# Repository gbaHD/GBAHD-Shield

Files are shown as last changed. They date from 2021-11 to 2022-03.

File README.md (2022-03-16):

# gbaHD Shield
This is a shield for the [gbaHD project](https://github.com/zwenergy/gbaHD).  

# What is the gbaHD Shield?
The gbaHD Shield is an easy solution to interface with the Spartan Edge Accelerator Board used for the gbaHD Project and the GBA / GBA-SP itself.

It has the following features.
- Connects via female headers to the Edge board (shield)
- Has a FFC 40 pin connector for OGBA LCD connector. Need Type-B Cable (Reverse) vvv=======^^^
- Has a FFC 32 pin connector for OGBA LCD connector. Need Type-B Cable (Reverse) vvv=======^^^
- Has a FFC 34 pin connector for GBA-SP LCD connector. Need Type-A Cable (Direct) vvv=======vvv
- Has a FFC 16 pin connector for controls with a wire up board. Need Type-B Cable (Reverse) vvv=======^^^
- Has a ATMEGA328p / ATMEGA168p / ATMEGA88p for using a SNES connector to control the GBA.
- Has a high-side switch for GBA power controls (IGR).
- Optional Flex-Cable to solder on the the CPU of the GBA and the GBASP
- Unused ATMEGA-Pins are broken out as testpoints on the top and bottom side for future features.

In cooperation with bbsan the featureset of the Shield has been expanded.
The new features are:
- Update of the ATMEGA Firmwre over the ESP32
- Bluetooth-Controller Support
- WebUI
- OTA-Update of the ESP32, ATMEGA and Bitstreams over the WebUI
- Bitstream selection (720p / 1080p) in the WebUI

## Special Thanks
- @zwenergy0 for the gbaHD-Project itself
- @bbsan2k for all the hard work with the ESP32-Side
- @ManCloud for the Shield design itself
- @jotheripper for the awesome cases (https://www.prusaprinters.org/social/170041-jotheripper/about)
- @ricardoquesada for the BluePad-Implementation (https://github.com/ricardoquesada/bluepad32)

## Contributing
If you wish to contribute, see something wrong or want to add a feature please make a pull request or leave an issue!

## BOM
|Reference	|Value |
|---	|---						|
|C1,C3	|100nF - 0805|
|C2	|22u - 0805|
|C4	|47uF - 0805|
|R1	|2.2k - 0805|
|R2,R7,R6	|1k - 0805|
|R3,R4,R8	|10K - 0805|
|R5	|500 - 0805|
|D1	|LED RED - 0805|
|D2	|LED GREEN - 0805|
|U1	|AZ1117R-ADJ - SOT-89-3|
|U2,U3	|74HC595 - SOIC-16|
|U4	|SNES_7PIN|
|U5	|ATmega328P-AU|
|U5-Alternative	|ATmega168P-AU|
|U5-Alternative-Alternative	|ATmega88PA-AU|
|Q1	|SI2301CDS-T1-GE3 - SOT-23|
|Q2,Q3	|2N7002 - SOT-23|
|SW1	|XKB-TS-1185EC-C-D-B|
|J2			|32Pin 0.5 Pitch, bottom contacts|
|J3			|34Pin 0.5 Pitch, bottom contacts|
|J4			|16Pin 0.5 Pitch, bottom contacts|
|J5			|40Pin 0.5 Pitch, bottom contacts|
|J6	|PinHeader 1x6 2.54mm|
|J7,J9	|PinHeader 1x8 2.54mm|
|J8,J10	|PinHeader 1x10 2.54mm|

## Images
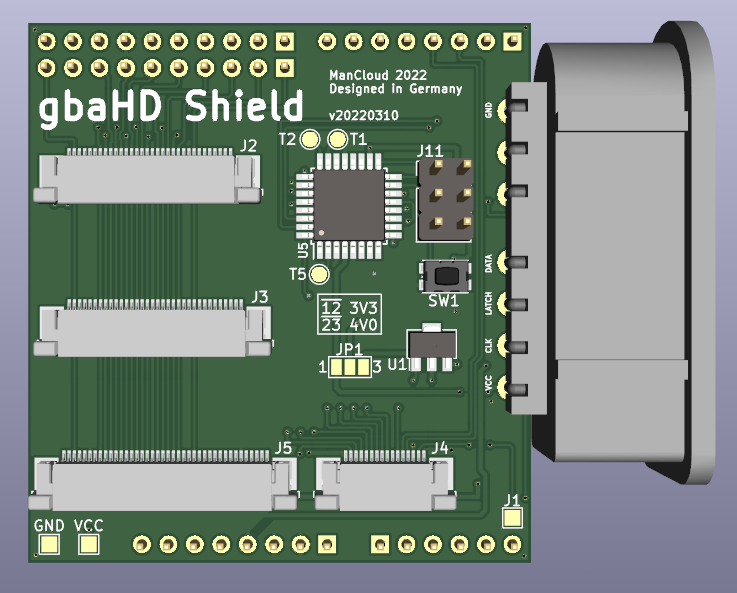
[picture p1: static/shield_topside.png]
PCB Top-Side PCB

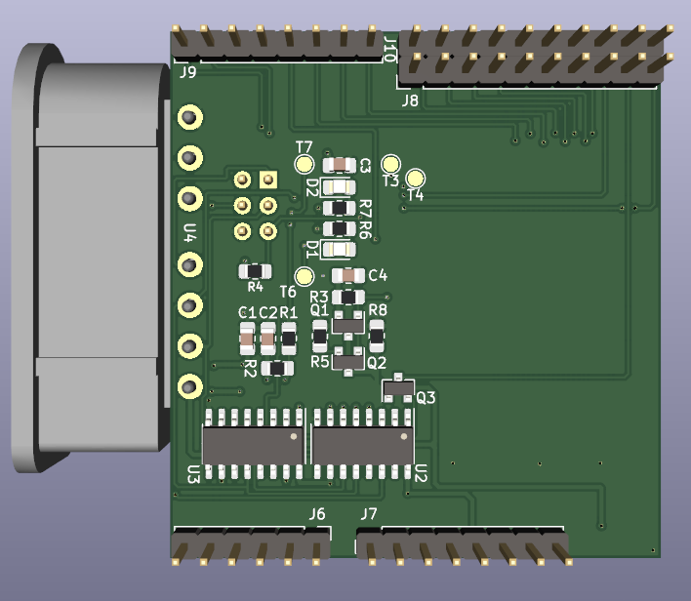
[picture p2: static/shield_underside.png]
PCB Under-Side PCB


Breakout-Board for the OGBA

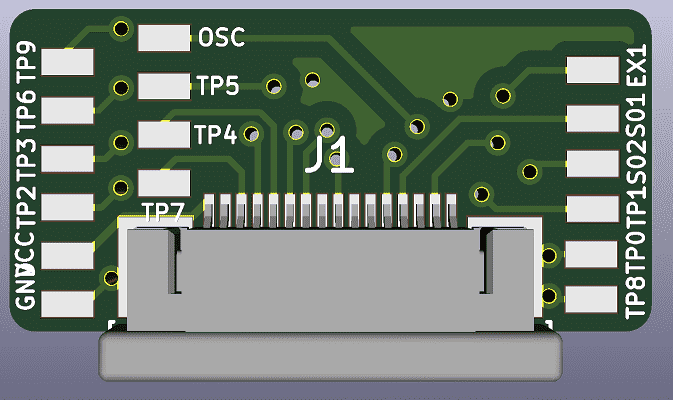
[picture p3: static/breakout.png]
Breakout OGBA Breakout PCB


Breakout-Board for the GBA-SP

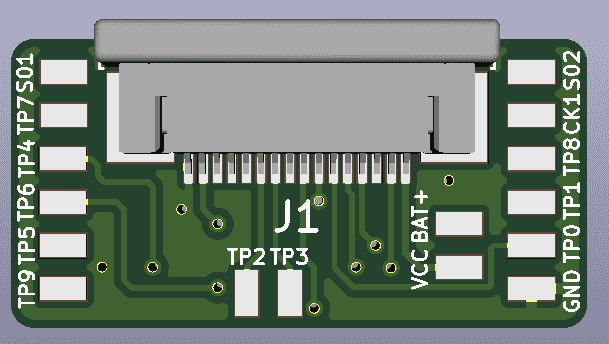
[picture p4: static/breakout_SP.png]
Breakout_GBA-SP Breakout PCB for GBA SP


Flex-Cable for the GBA

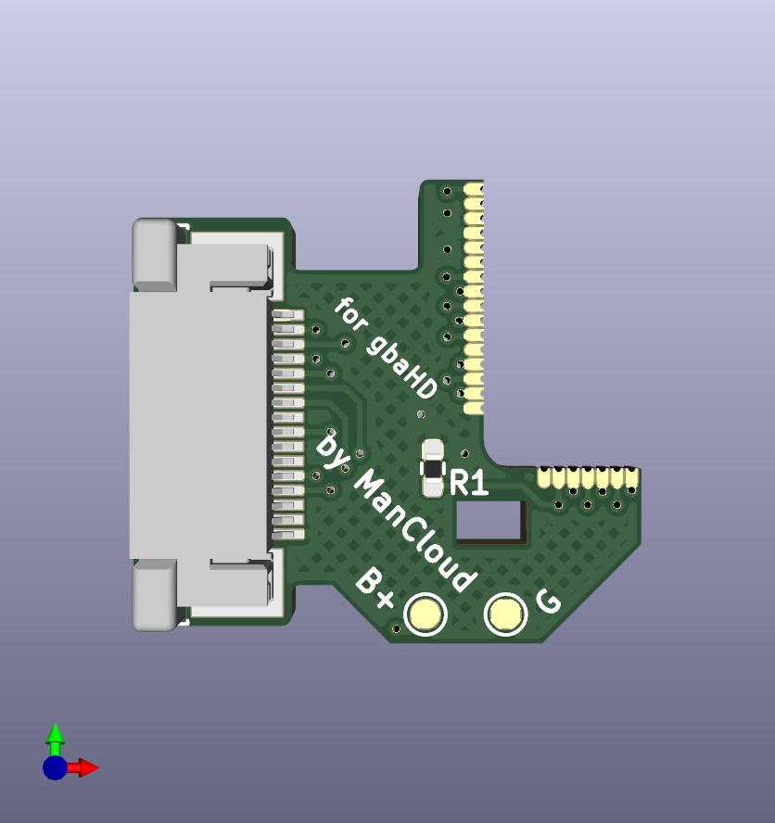
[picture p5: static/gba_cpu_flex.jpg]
Breakout_GBA-SP Flex for the GBA CPU


Flex-Cable for the GBA-SP

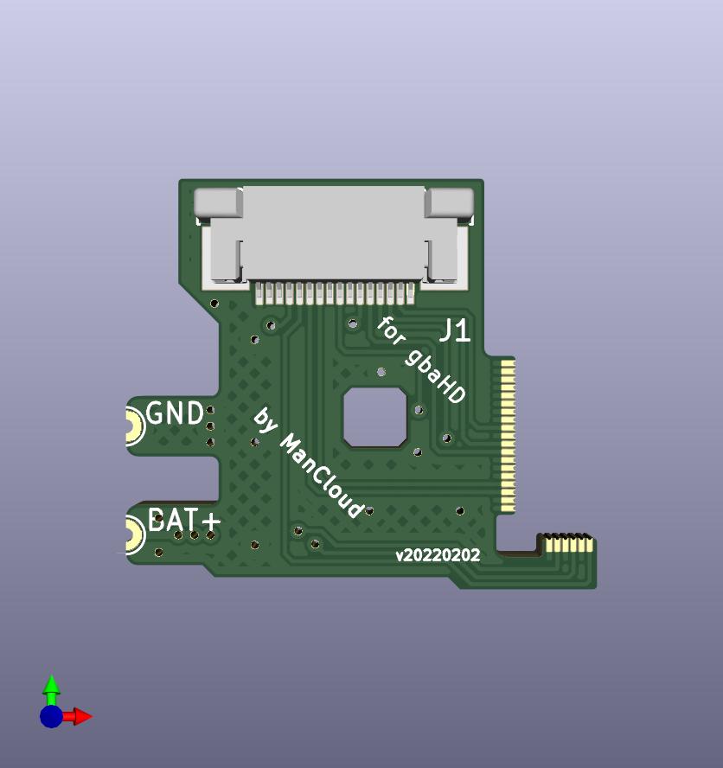
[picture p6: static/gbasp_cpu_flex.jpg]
Breakout_GBA-SP Flex for the GBA CPU


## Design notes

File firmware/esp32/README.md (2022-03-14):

# gbaHD ESP32 Software for SAE board

This folder contains the ESP32 Software for usage with zwenergys gbaHD project.

## Features:

**Bluetooth Controller Support:**

The ESP32 Micro Controller contains an onboard wireless and Bluetooth Modem.
This Bluetooth Modem can be used to connect with a Wireless Bluetooth Controller.
This project makes use of Ricardo Quesadas *Bluepad32* library (see [2]) for the whole Bluetooth Controller communication setup.
Furthermore it uses TWI to communicate all key presses to the ATMega on the gbaHD Shield, which then publishs the key presses to the GBA.
A simplified mapping is provided in the *Settings* tab on gbaHDs Web Interface.

**OTA Update:**

To simplify all further updates by zwenergy or for the esp32, OTA functionality was added.
When opening the Web Interface on http://gbahd.local it automatically checks, if a new bitstream update or a new esp32 software is available. You can directly update using the *OTA Update* Button on the Web Interface.
To connect to a WiFi network, create a file called "wifi.cfg" with your wifi credentials on an sd card. Insert it and connection to this network will be established:
```
ssid=MyWifiSSID
password=MyWifiPasswordIsSecure
```

**SD Card Update:**

If you want to keep your device offline but still want to experience the latest and greatest features, you can simply add all Update files to SD Card. On the first boot afterwards, gbaHD will then copy these updates to its internal memory.

File            |   Update
----------------|------------
esp32.bin       | ESP32
spiffs.bin      | ESP32 data partition
720p.bit        | 720P Bitstream
1080p.bit       | 1080P Bitstream

**Bitstream Selection:**

As per default, gbaHD will be started with the 720P Bitstream. In the *Settings* tab of the Web Interface, you can change it to 1080P.

## Thanks to...

- Zwenergy for gbaHD [1]
- ManCloud for coordination and gbaHD shield
- Ricardo Quesada for Bluepad32 [2]
- Arduino and Espressif for arduino-esp32
- PicoCSS team for PicoCSS [3]
- jotheripper for his gbaHD Case
- derKevin for test feedback
- bbsan for ESP32 SW

[1] gbaHD:
https://github.com/zwenergy/gbaHD

[2] Bluepad32:
https://gitlab.com/ricardoquesada/bluepad32

[3] PicoCSS:
https://picocss.com

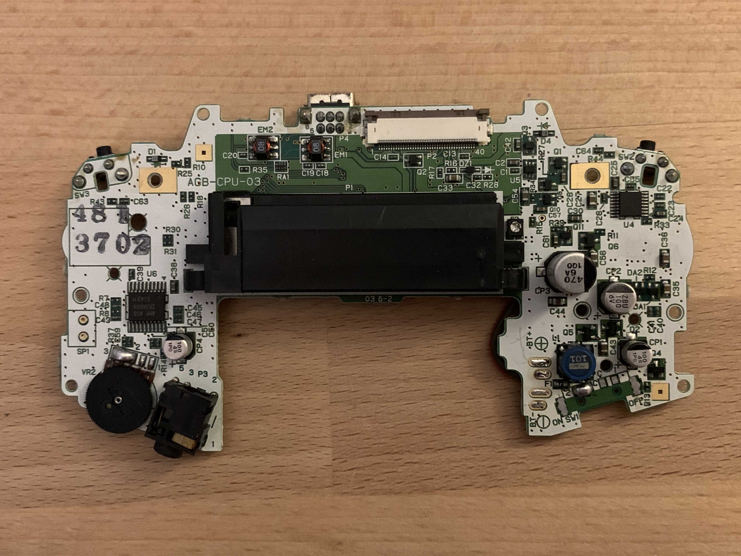
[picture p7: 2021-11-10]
static/wiki/ogba_overview_underside.jpg

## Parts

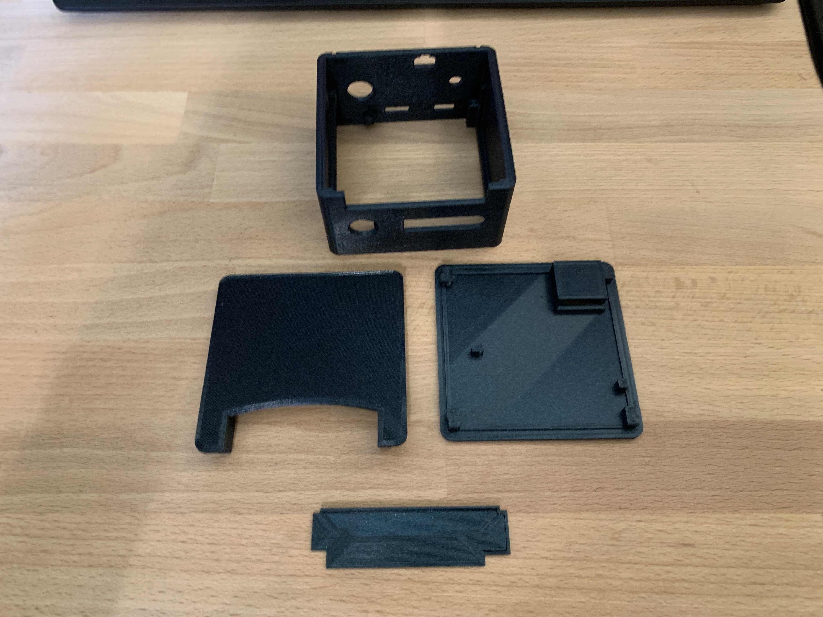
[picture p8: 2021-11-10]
static/wiki/case_sp/case0_parts1.jpg

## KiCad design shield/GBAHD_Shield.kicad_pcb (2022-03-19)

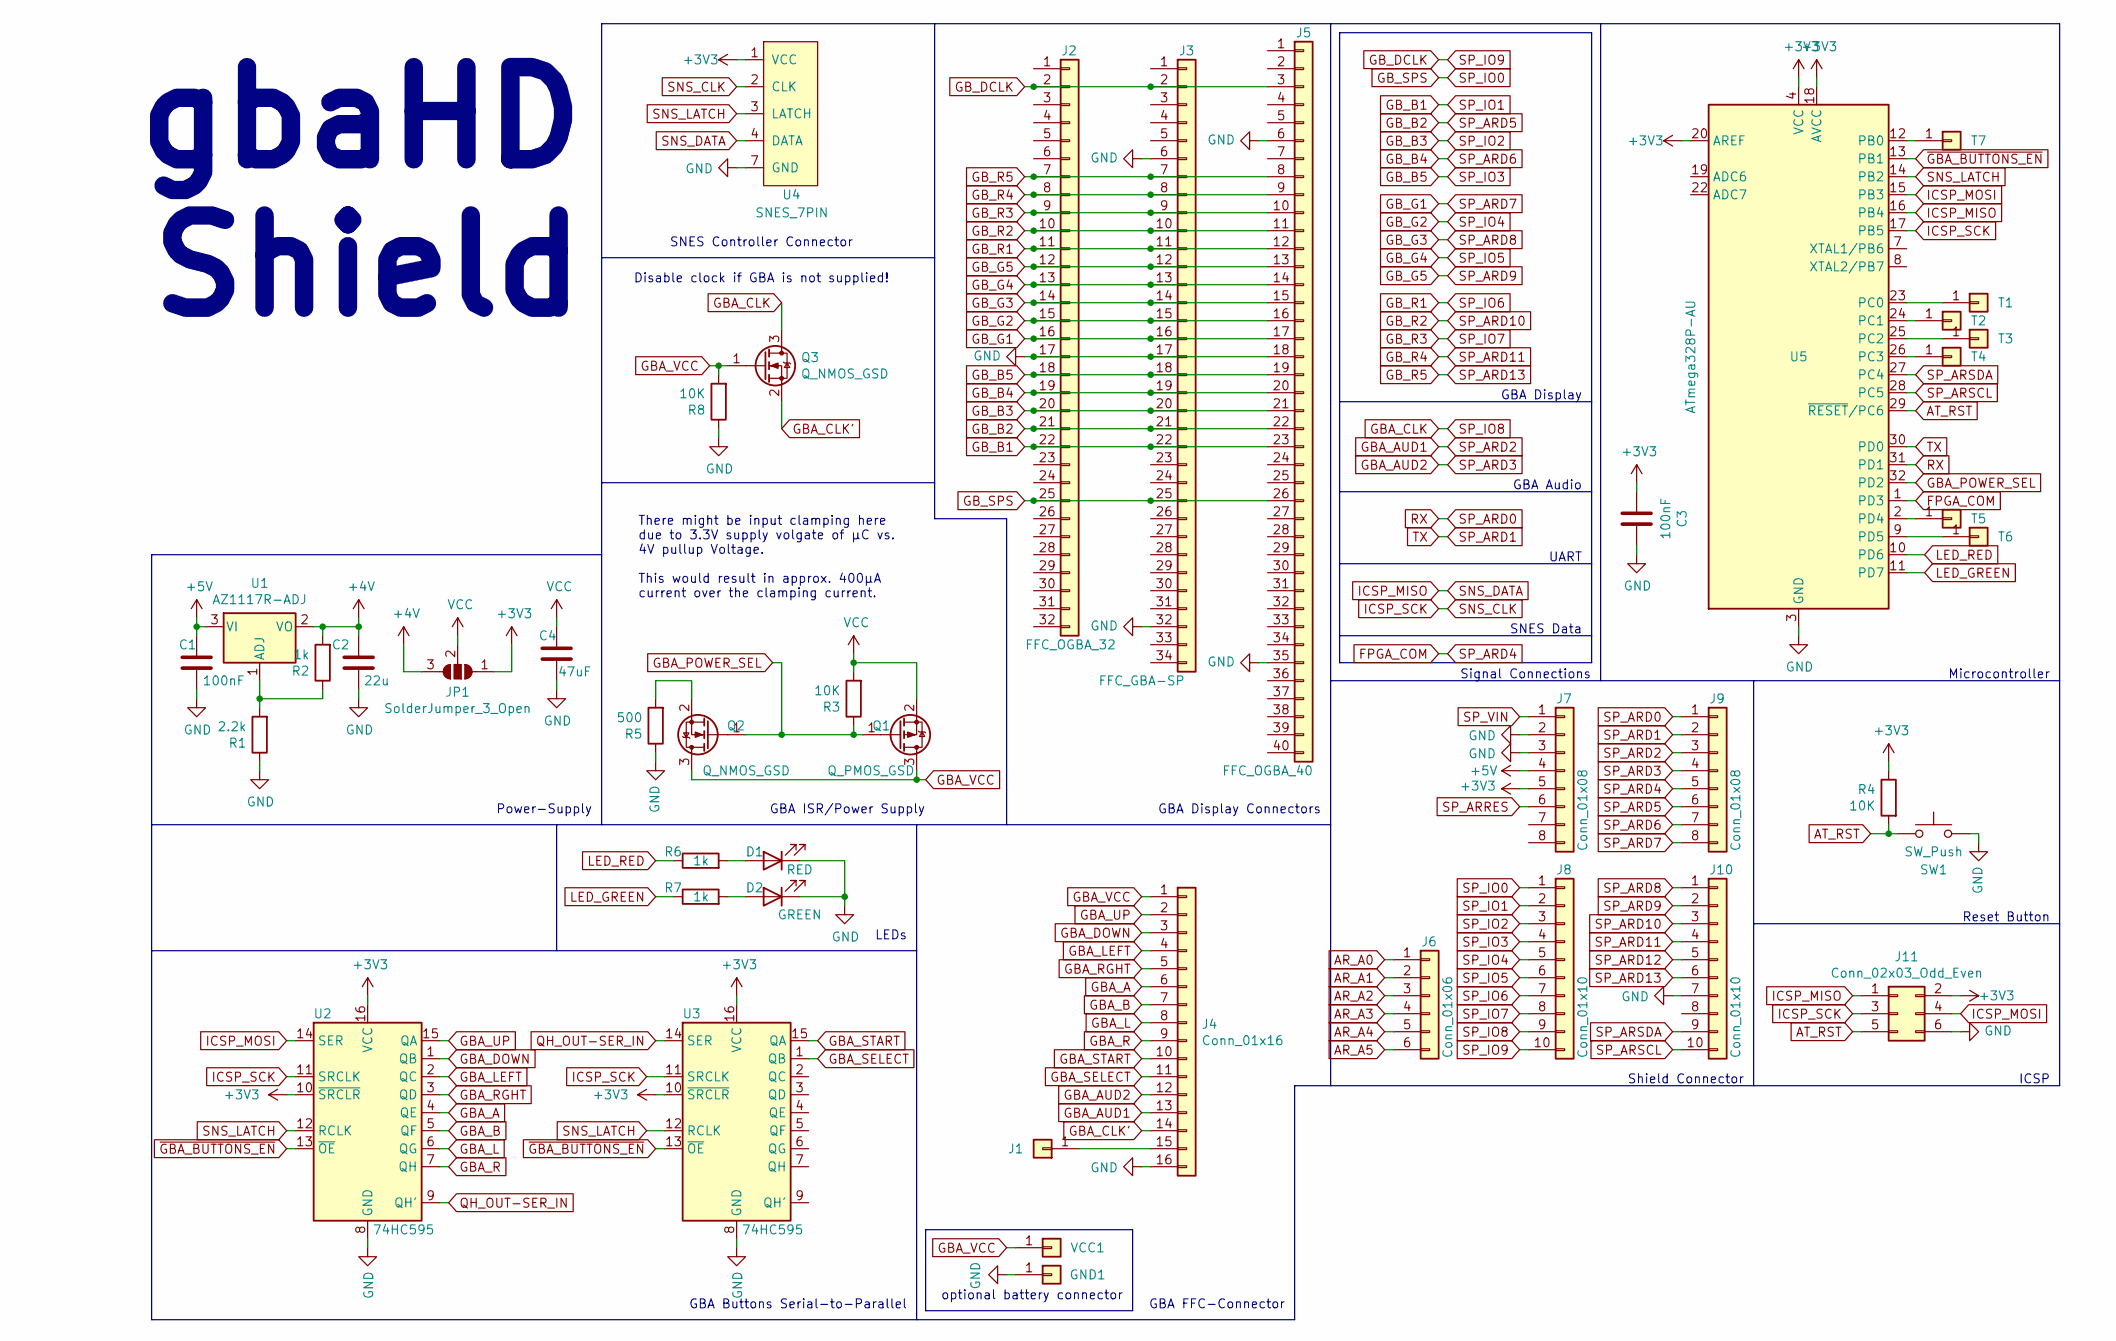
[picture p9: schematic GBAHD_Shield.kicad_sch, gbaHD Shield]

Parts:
C1, C3: 100nF; C_0805_2012Metric_Pad1.18x1.45mm_HandSolder
C2: 22u; C_0805_2012Metric_Pad1.18x1.45mm_HandSolder
C4: 47uF; C_0805_2012Metric_Pad1.18x1.45mm_HandSolder
D1: RED; LED_0805_2012Metric_Pad1.15x1.40mm_HandSolder
D2: GREEN; LED_0805_2012Metric_Pad1.15x1.40mm_HandSolder
GND1: Conn_01x01; TestPoint_Pad_1.5x1.5mm
J1: Conn_01x01; TestPoint_Pad_1.5x1.5mm
J2: FFC_OGBA_32; TE_3-1734839-2_1x32-1MP_P0.5mm_Horizontal
J3: FFC_GBA-SP; TE_3-1734839-4_1x34-1MP_P0.5mm_Horizontal
J4: Conn_01x16; TE_1-1734839-6_1x16-1MP_P0.5mm_Horizontal
J5: FFC_OGBA_40; TE_4-1734839-0_1x40-1MP_P0.5mm_Horizontal
J6: Conn_01x06; PinHeader_1x06_P2.54mm_Vertical
J7, J9: Conn_01x08; PinHeader_1x08_P2.54mm_Vertical
J8, J10: Conn_01x10; PinHeader_1x10_P2.54mm_Vertical
J11: Conn_02x03_Odd_Even; PinHeader_2x03_P2.54mm_Vertical
JP1: SolderJumper_3_Open; SolderJumper-3_P1.3mm_Open_Pad1.0x1.5mm_NumberLabels
Q1: Q_PMOS_GSD; SOT-23
Q2, Q3: Q_NMOS_GSD; SOT-23
R1: 2.2k; R_0805_2012Metric_Pad1.20x1.40mm_HandSolder
R2, R6, R7: 1k; R_0805_2012Metric_Pad1.20x1.40mm_HandSolder
R3, R4, R8: 10K; R_0805_2012Metric_Pad1.20x1.40mm_HandSolder
R5: 500; R_0805_2012Metric_Pad1.20x1.40mm_HandSolder
SW1: SW_Push; SW_Push_1P1T_NO_CK_KMR2
T1, T2, T3, T4, T5, T6, T7: Conn_01x01; TestPoint_Pad_D1.5mm
U1: AZ1117R-ADJ; SOT-89-3
U2, U3: 74HC595; SOIC-16_3.9x9.9mm_P1.27mm
U4: SNES_7PIN
U5: ATmega328P-AU; TQFP-32_7x7mm_P0.8mm
VCC1: Conn_01x01; TestPoint_Pad_1.5x1.5mm

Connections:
+3V3: C3.2, J7.5, J11.2, JP1.1 (A), R4.1, U2.10 (~SRCLR), U2.16 (VCC), U3.10 (~SRCLR), U3.16 (VCC), U4.1 (VCC), U5.4 (VCC), U5.6 (VCC), U5.18 (AVCC), U5.20 (AREF)
+4V: C2.2, JP1.3 (B), R2.2, U1.2 (VO)
+5V: C1.2, J7.4, U1.3 (VI)
AR_A0: J6.1
AR_A1: J6.2
AR_A2: J6.3
AR_A3: J6.4
AR_A4: J6.5
AR_A5: J6.6
AT_RST: J11.5, R4.2, SW1.1, U5.29 (~RESET/PC6)
FPGA_COM: J9.5, U5.1 (PD3)
GBA_A: J4.6, U2.4 (QE)
GBA_AUD1: J4.13, J9.3
GBA_AUD2: J4.12, J9.4
GBA_B: J4.7, U2.5 (QF)
GBA_CLK: J8.9, Q3.3 (D)
GBA_CLK': J4.14, Q3.2 (S)
GBA_DOWN: J4.3, U2.1 (QB)
GBA_L: J4.8, U2.6 (QG)
GBA_LEFT: J4.4, U2.2 (QC)
GBA_POWER_SEL: Q1.1 (G), Q2.1 (G), R3.1, U5.32 (PD2)
GBA_R: J4.9, U2.7 (QH)
GBA_RGHT: J4.5, U2.3 (QD)
GBA_SELECT: J4.11, U3.1 (QB)
GBA_START: J4.10, U3.15 (QA)
GBA_UP: J4.2, U2.15 (QA)
GBA_VCC: J4.1, Q1.3 (D), Q2.3 (D), Q3.1 (G), R8.2, VCC1.1
GB_B1: J2.22, J3.22, J5.23, J8.2
GB_B2: J2.21, J3.21, J5.22, J9.6
GB_B3: J2.20, J3.20, J5.21, J8.3
GB_B4: J2.19, J3.19, J5.20, J9.7
GB_B5: J2.18, J3.18, J5.19, J8.4
GB_DCLK: J2.2, J3.2, J5.3, J8.10
GB_G1: J2.16, J3.16, J5.17, J9.8
GB_G2: J2.15, J3.15, J5.16, J8.5
GB_G3: J2.14, J3.14, J5.15, J10.1
GB_G4: J2.13, J3.13, J5.14, J8.6
GB_G5: J2.12, J3.12, J5.13, J10.2
GB_R1: J2.11, J3.11, J5.12, J8.7
GB_R2: J2.10, J3.10, J5.11, J10.3
GB_R3: J2.9, J3.9, J5.10, J8.8
GB_R4: J2.8, J3.8, J5.9, J10.4
GB_R5: J2.7, J3.7, J5.8, J10.6
GB_SPS: J2.25, J3.25, J5.26, J8.1
GND: C1.1, C2.1, C3.1, C4.1, D1.1 (K), D2.1 (K), GND1.1, J2.17, J3.6, J3.17, J3.32, J4.16, J5.6, J5.18, J5.35, J7.2, J7.3, J10.7, J11.6, R1.1, R5.1, R8.1, SW1.2, U2.8 (GND), U3.8 (GND), U4.7 (GND), U5.3 (GND), U5.5 (GND), U5.21 (GND)
ICSP_MISO: J11.1, U4.4 (DATA), U5.16 (PB4)
ICSP_MOSI: J11.4, U2.14 (SER), U5.15 (PB3)
ICSP_SCK: J11.3, U2.11 (SRCLK), U3.11 (SRCLK), U4.2 (CLK), U5.17 (PB5)
LED_GREEN: R7.1, U5.11 (PD7)
LED_RED: R6.1, U5.10 (PD6)
unnamed: D1.2 (A), R6.2
unnamed: D2.2 (A), R7.2
unnamed: J1.1, J4.15
unnamed: Q2.2 (S), R5.2
unnamed: R1.2, R2.1, U1.1 (ADJ)
unnamed: T1.1, U5.23 (PC0)
unnamed: T2.1, U5.24 (PC1)
unnamed: T3.1, U5.25 (PC2)
unnamed: T4.1, U5.26 (PC3)
unnamed: T5.1, U5.2 (PD4)
unnamed: T6.1, U5.9 (PD5)
unnamed: T7.1, U5.12 (PB0)
QH_OUT-SER_IN: U2.9 (QH'), U3.14 (SER)
RX: J9.1, U5.31 (PD1)
SNS_LATCH: U2.12 (RCLK), U3.12 (RCLK), U4.3 (LATCH), U5.14 (PB2)
SP_ARD1: J9.2, U5.30 (PD0)
SP_ARD12: J10.5
SP_ARRES: J7.6
SP_ARSCL: J10.10, U5.28 (PC5)
SP_ARSDA: J10.9, U5.27 (PC4)
SP_VIN: J7.1
VCC: C4.2, JP1.2 (C), Q1.2 (S), R3.2
~GBA_BUTTONS_EN: U2.13 (~OE), U3.13 (~OE), U5.13 (PB1)

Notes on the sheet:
ICSP
GBA Buttons Serial-to-Parallel
GBA FFC-Connector
GBA ISR/Power Supply
SNES Data
optional battery connector
There might be input clamping here due to 3.3V supply volgate of µC vs. 4V pullup Voltage. This would result in approx. 400µA current over the clamping current.
Microcontroller
GBA Display Connectors
Shield Connector
gbaHD Shield
UART
LEDs
Power-Supply
Disable clock if GBA is not supplied!
SNES Controller Connector
Reset Button
Signal Connections
GBA Display
GBA Audio

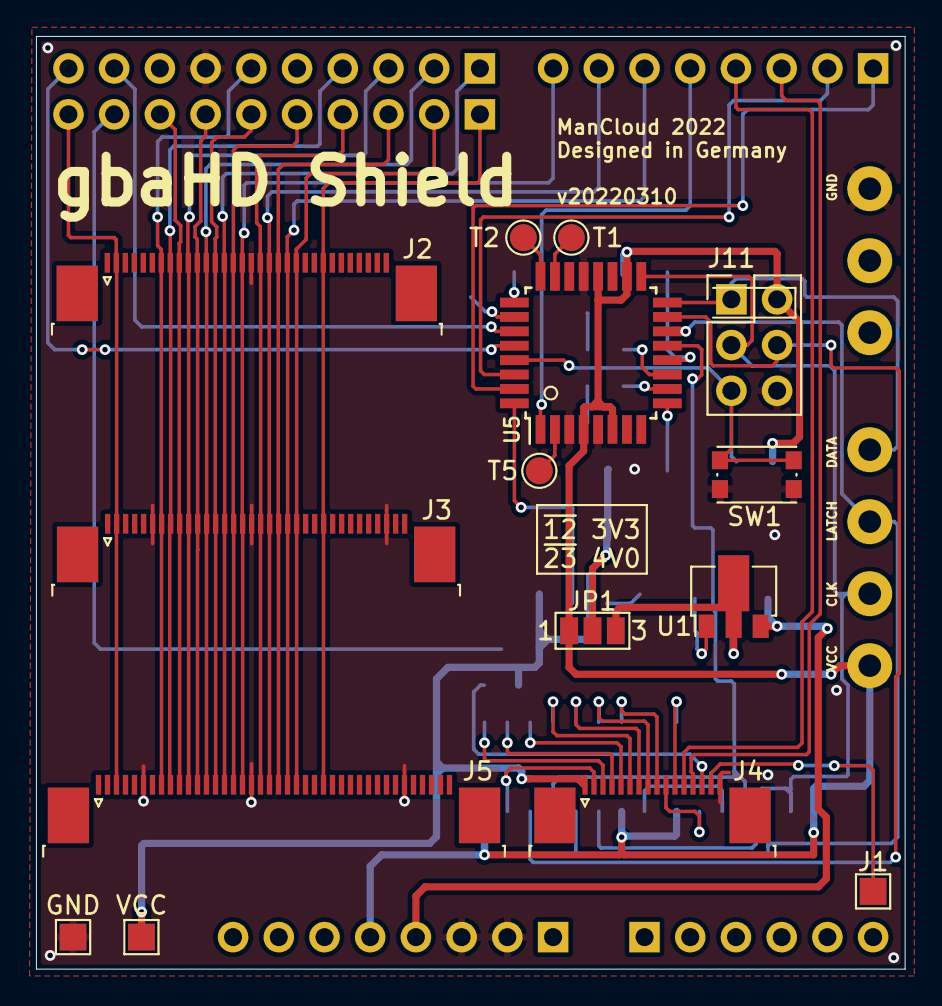
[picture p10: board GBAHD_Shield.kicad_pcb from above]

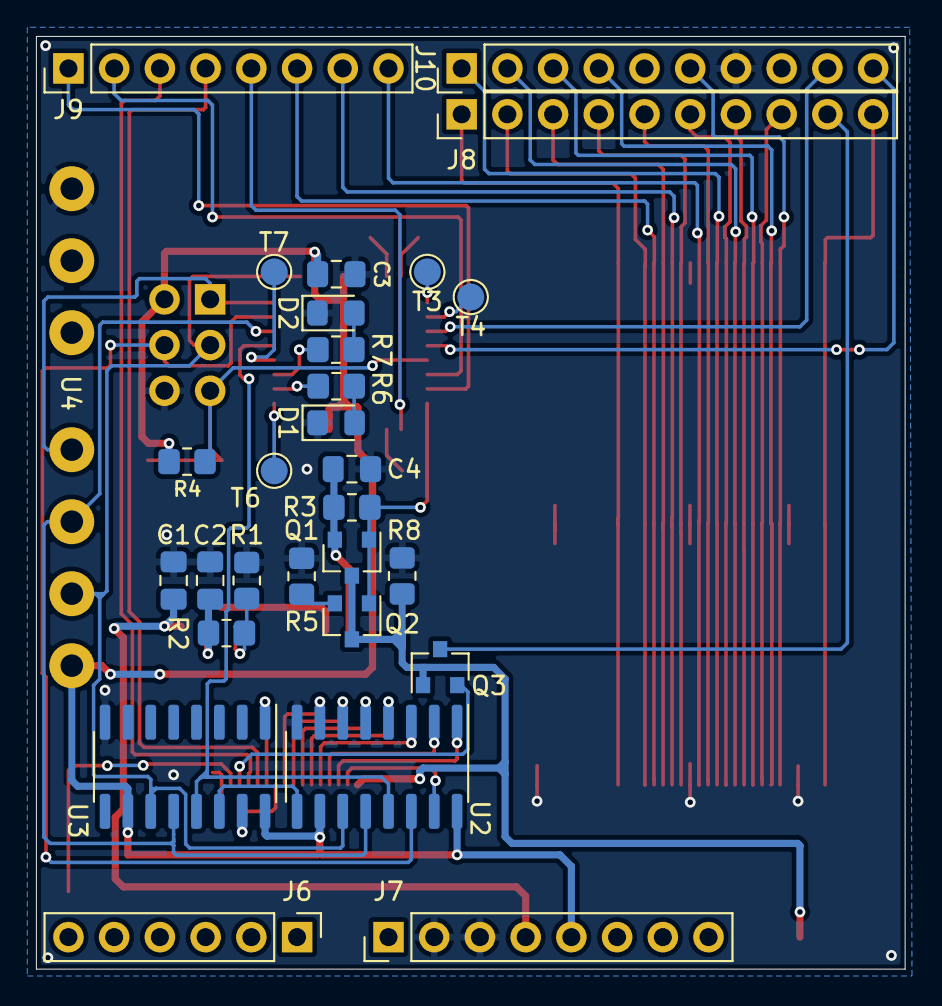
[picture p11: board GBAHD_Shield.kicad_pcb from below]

Board: 2 copper layers, 48.3 x 51.8 mm, 44 parts (29 on the bottom side), 64 nets.

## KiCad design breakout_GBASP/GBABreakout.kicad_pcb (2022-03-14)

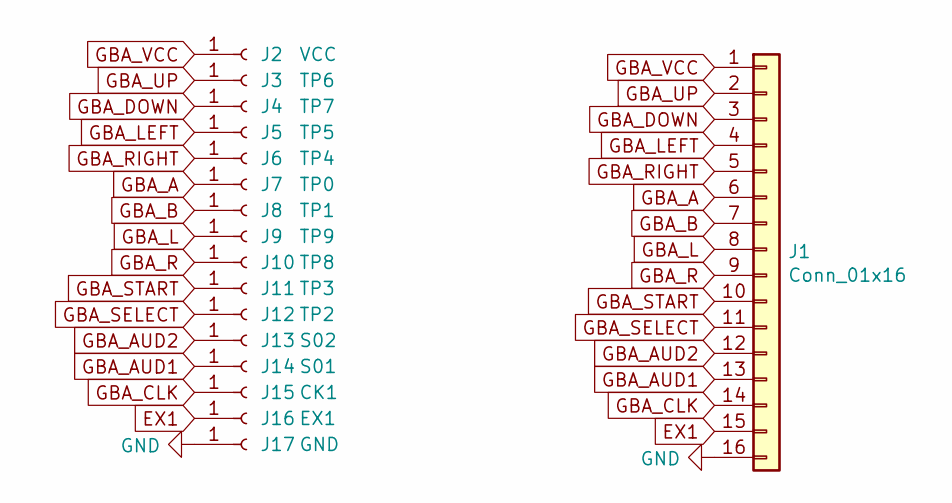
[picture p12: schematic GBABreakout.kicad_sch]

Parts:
J1: Conn_01x16; TE_1-1734839-6_1x16-1MP_P0.5mm_Horizontal
J2: VCC; SOLDER_PAD
J3: TP6; SOLDER_PAD
J4: TP7; SOLDER_PAD
J5: TP5; SOLDER_PAD
J6: TP4; SOLDER_PAD
J7: TP0; SOLDER_PAD
J8: TP1; SOLDER_PAD
J9: TP9; SOLDER_PAD
J10: TP8; SOLDER_PAD
J11: TP3; SOLDER_PAD
J12: TP2; SOLDER_PAD
J13: S02; SOLDER_PAD
J14: S01; SOLDER_PAD
J15: CK1; SOLDER_PAD
J16: EX1; SOLDER_PAD
J17: GND; SOLDER_PAD

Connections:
EX1: J1.15, J16.1
GBA_A: J1.6, J7.1
GBA_AUD1: J1.13, J14.1
GBA_AUD2: J1.12, J13.1
GBA_B: J1.7, J8.1
GBA_CLK: J1.14, J15.1
GBA_DOWN: J1.3, J4.1
GBA_L: J1.8, J9.1
GBA_LEFT: J1.4, J5.1
GBA_R: J1.9, J10.1
GBA_RIGHT: J1.5, J6.1
GBA_SELECT: J1.11, J12.1
GBA_START: J1.10, J11.1
GBA_UP: J1.2, J3.1
GBA_VCC: J1.1, J2.1
GND: J1.16, J17.1

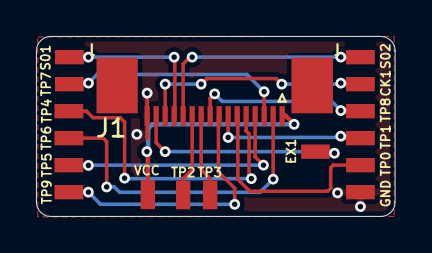
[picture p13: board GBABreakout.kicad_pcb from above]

Board: 2 copper layers, 19.9 x 10.0 mm, 17 parts (0 on the bottom side), 16 nets.

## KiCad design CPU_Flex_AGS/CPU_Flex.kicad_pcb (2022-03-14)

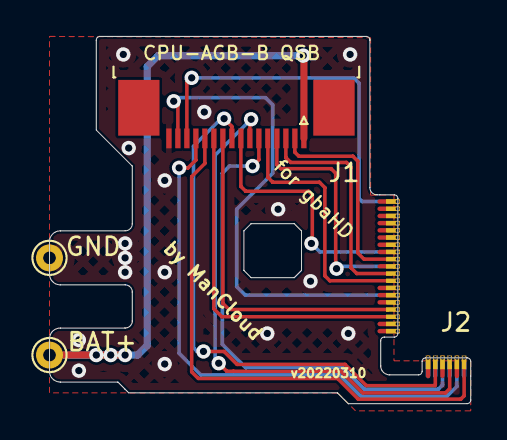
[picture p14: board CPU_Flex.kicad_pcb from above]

Board: 2 copper layers, 23.4 x 20.4 mm, 4 parts (0 on the bottom side), 16 nets.

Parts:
BAT+: Conn_01x01; TestPoint_THTPad_D1.5mm_Drill0.7mm
GND: Conn_01x01; TestPoint_THTPad_D1.5mm_Drill0.7mm
J1: Conn_01x16; TE_1-1734839-6_1x16-1MP_P0.5mm_Horizontal
J2: CPU AGB B Interface; CPU_AGB_B_Interface

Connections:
/GBA_A: J1.6, J2.3 (TP0)
/GBA_AUD_L: J1.12, J2.6 (S02)
/GBA_AUD_R: J1.13, J2.5 (S01)
/GBA_B: J1.7, J2.4 (TP1)
/GBA_CLK: J1.14, J2.138 (CK1)
/GBA_DOWN: J1.3, J2.148 (TP7)
/GBA_L: J1.8, J2.145 (TP9)
/GBA_LEFT: J1.4, J2.147 (TP5)
/GBA_R: J1.9, J2.2 (TP8)
/GBA_RESET: J1.15, J2.151 (RESET)
/GBA_RIGHT: J1.5, J2.149 (TP4)
/GBA_SELECT: J1.11, J2.154 (TP2)
/GBA_START: J1.10, J2.153 (TP3)
/GBA_UP: J1.2, J2.146 (TP6)
GND: GND.1, J1.16
VCC: BAT+.1, J1.1

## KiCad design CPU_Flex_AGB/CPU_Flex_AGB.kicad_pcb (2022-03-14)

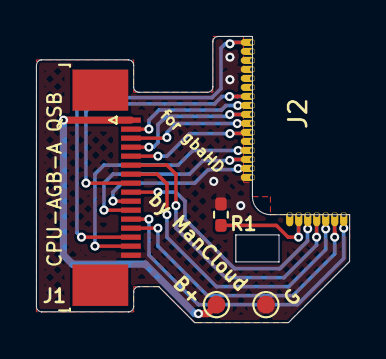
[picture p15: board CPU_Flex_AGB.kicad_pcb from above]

Board: 2 copper layers, 17.4 x 15.9 mm, 5 parts (0 on the bottom side), 17 nets.

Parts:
B+: BAT+; TestPoint_Pad_D1.0mm
G: GND; TestPoint_Pad_D1.0mm
J1: Conn_01x16; TE_1-1734839-6_1x16-1MP_P0.5mm_Horizontal
J2: CPU_AGB_A_Interface; CPU_AGB_A_INTERFACE
R1: 100k; R_0402_1005Metric_Pad0.72x0.64mm_HandSolder

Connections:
GND: G.1, J1.16, J2.116 (GND), J2.128 (GND), R1.1
unnamed: J1.2, J2.120 (TP6)
unnamed: J1.3, J2.122 (TP7)
unnamed: J1.4, J2.121 (TP5)
unnamed: J1.5, J2.123 (TP4)
unnamed: J1.6, J2.4 (TP0)
unnamed: J1.7, J2.5 (TP1)
unnamed: J1.8, J2.119 (TP9)
unnamed: J1.9, J2.3 (TP8)
unnamed: J1.10, J2.127 (TP3)
unnamed: J1.11, J2.126 (TP2)
unnamed: J1.12, J2.7 (S02)
unnamed: J1.13, J2.6 (S01)
unnamed: J1.14, J2.113 (CK1)
unnamed: J1.15, J2.125 (RESET)
unnamed: J2.2 (IN35), R1.2
VCC: B+.1, J1.1

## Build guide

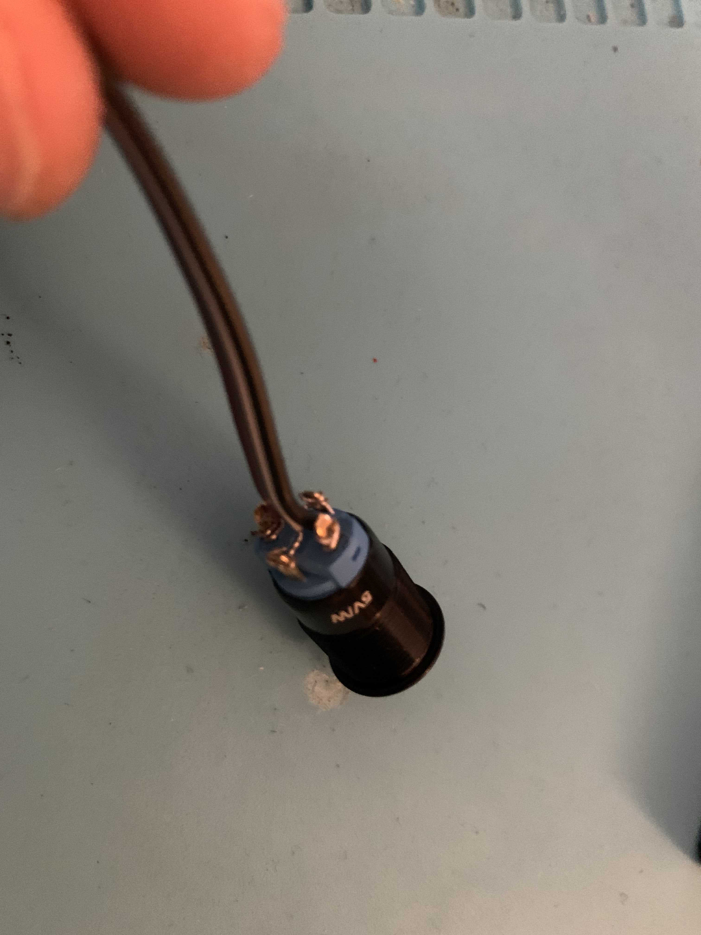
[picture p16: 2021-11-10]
static/wiki/case_sp/switch-solderedwires.jpg

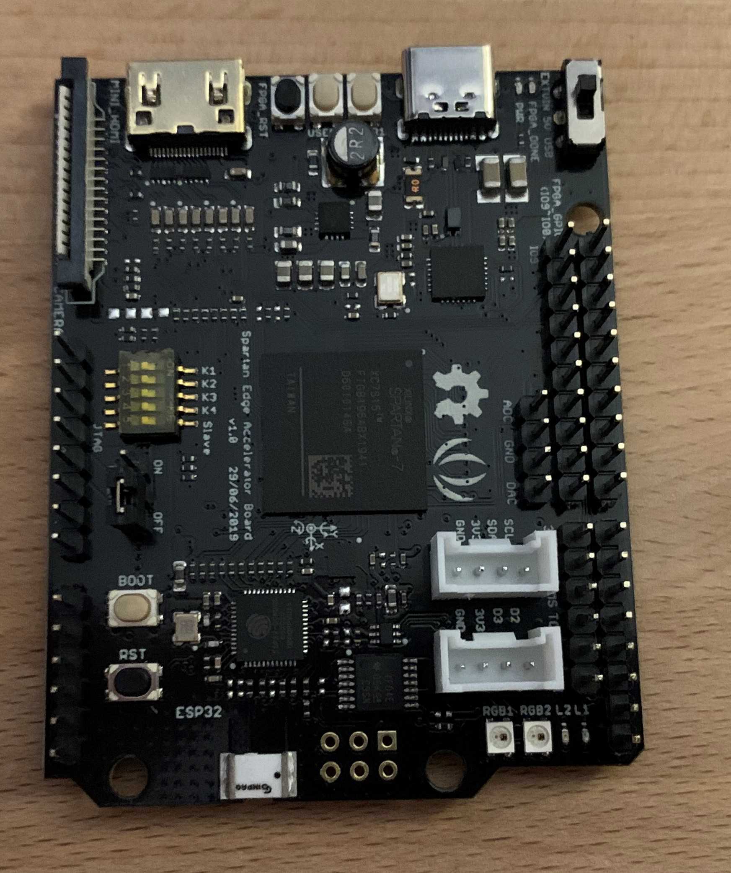
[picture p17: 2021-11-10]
static/wiki/spartan_w_pins_soldered.jpg

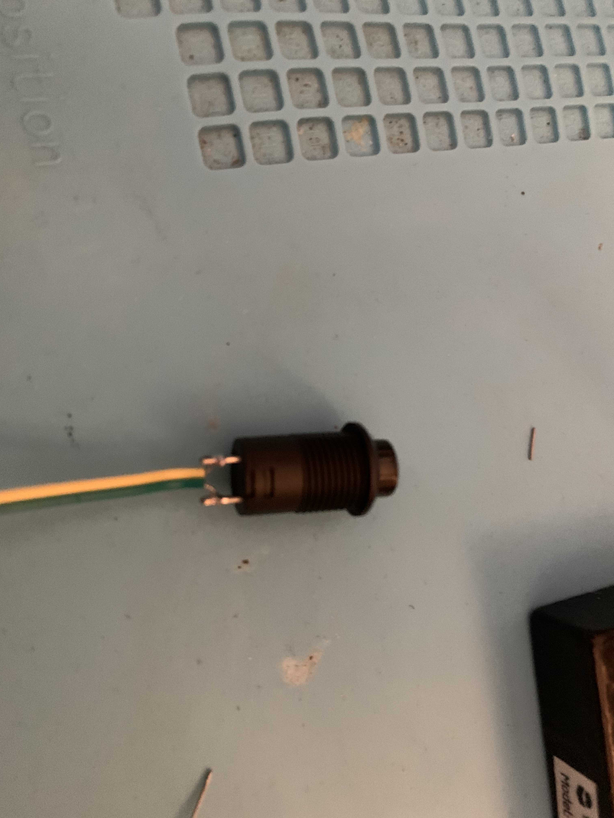
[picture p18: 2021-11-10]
static/wiki/case_sp/switch-reset-solderedwires.jpg

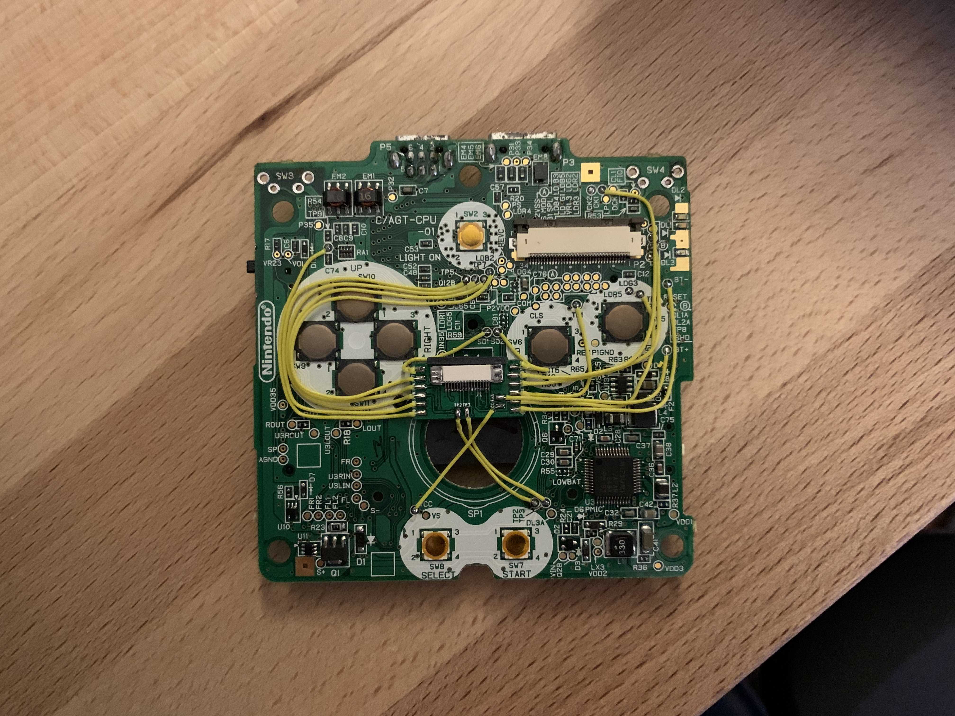
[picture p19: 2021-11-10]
static/wiki/sp_soldered.jpg

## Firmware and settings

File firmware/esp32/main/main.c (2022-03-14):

/*******************************************************************************
  ; -----------------------------------------------------------------------
   gbaHD-ESP32 for zwenergys gbaHD

   MIT License

   Copyright (c) 2021 Alexander Kreutz

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
 *******************************************************************************/

#include <stddef.h>

#include "sdkconfig.h"

#include <btstack_port_esp32.h>
#include <btstack_run_loop.h>
#include <hci_dump.h>
#include <uni_esp32.h>
#include <uni_main.h>


int app_main(void) {
  // hci_dump_open(NULL, HCI_DUMP_STDOUT);

  uni_esp32_enable_uart_output(0);

  // Configure BTstack for ESP32 VHCI Controller
  btstack_init();

  // Init Bluepad32
  uni_main(0, NULL);

  return 0;
}

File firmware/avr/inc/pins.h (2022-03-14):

/*
 * pins.h
 *
 *  Created on: 02.01.2022
 *      Author: ManCloud
 */

#ifndef PINS_H_
#define PINS_H_

/* === INCLUDES ============================================================= */

/* === TYPES ================================================================ */

/* === MACROS =============================================================== */
#define GBA_OUTPUT_EN_DIR       DDRB
#define GBA_OUTPUT_EN_PORT      PORTB
#define GBA_OUTPUT_EN_PIN       PIN1
#define GBA_OUTPUT_EN_INIT_M()  DDRB |= _BV(GBA_OUTPUT_EN_PIN)
#define GBA_OUTPUT_EN_M(enable) GBA_OUTPUT_EN_PORT = ((GBA_OUTPUT_EN_PORT & ~_BV(GBA_OUTPUT_EN_PIN)) | ((enable) ? 0 : _BV(GBA_OUTPUT_EN_PIN)))

#define CTRL_DIR        DDRB
#define CTRL_PORT       PORTB
#define CTRL_LATCH      PIN2
#define GBA_DATA_OUT    PIN3
#define CTRL_DATA_IN    PIN4
#define CTRL_CLOCK      PIN5
#define CTRL_INIT_M()   CTRL_DIR |= _BV(CTRL_LATCH) | _BV(GBA_DATA_OUT) | _BV(CTRL_CLOCK)

#define LED_DIR         DDRD
#define LED_PORT        PORTD
#define LED_RED_PIN     PIN6
#define LED_GREEN_PIN   PIN7

#define GBA_POWER_ON_DIR    DDRD
#define GBA_POWER_ON_PIN    PIN2
#define GBA_POWER_ON_M()    GBA_POWER_ON_DIR |= _BV(GBA_POWER_ON_PIN)
#define GBA_POWER_OFF_M()   GBA_POWER_ON_DIR &= ~_BV(GBA_POWER_ON_PIN)

#define FPGA_COMM_DIR   DDRD
#define FPGA_COMM_PORT  PORTD
#define FPGA_COMM_PIN   PIN3

/* === GLOBALS ============================================================== */

/* === PROTOTYPES =========================================================== */

#endif //FW_H_

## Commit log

2021-01-21 Moved folders, added breakout board.
    [GBABreakout-B_Cu.gbr, GBABreakout-B_Mask.gbr, GBABreakout-B_Paste.gbr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]
2021-01-24 Added simple BOM
2021-01-24 Added BOM and programming info
2021-01-24 Removed old BOM
2021-03-19 Updated shield PCB and readme
    [GBAHD_Shield-B_Cu.gbr, GBAHD_Shield-B_Mask.gbr, GBAHD_Shield-B_Paste.gbr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]
2021-03-21 Updated to "Full-Shield"
    * changed supplies to 3V3 and 4V0
    * added pads for BAT connection
    * added 32-Pin FFC Connector
    [GBAHD_Shield-B_Cu.gbr, GBAHD_Shield-B_Mask.gbr, GBAHD_Shield-B_Paste.gbr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]
2021-04-05 Major Updates
    * Added QSB for GBA SP
    * Fixed wrong supply voltare for Components in case of SP setup
    [GBABreakout-B_Cu.gbr, GBABreakout-B_Mask.gbr, GBABreakout-B_Paste.gbr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]
2021-04-15 Updated Firmware to Support OE-Pin of 74HC595
2021-04-16 some minor changes
    * improved SP compatibility
    * changed via diameter to 0.6mm and holesize to 0.3mm
    * updated Readme
    [GBABreakout-B_Cu.gbr, GBABreakout-B_Mask.gbr, GBABreakout-B_Paste.gbr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]
2021-06-12 changed IGR combo, added filter restore combo, fixed no-controller handling
2021-06-13 sp-case pictures
    sp-case pictures
2021-07-11 Update README.md
    Fixed wrong part case for U2,U3
2021-07-19 2nd case-pictures
2022-03-14 Develop (#16)
    * Remove get_components from Makefile, fix bluepad path
    * Fixed naming of submodule
    * Fixed submodule mess
    * Removed bluepad32
    * Re-Add Bluepad32 properly
    * Update Build for adding web/bitstream handler
    * Add implementation for web handler and bitstream handler
    * Update arduino version
    * Fix build by using bluepad template as component foundation
    * Removed bluepad submodule
    * Copying default component files
    * Remove get_components
    * Improved over all build config
    * Overall refactoring and added wifi and mega handler
    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
    [CPU_Flex.kicad_pcb, CPU_Flex.kicad_sch, CPU_Flex_AGB.kicad_pcb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]
2022-03-16 updated shield production files
    [GBAHD_Shield-B_Cu.gbr, GBAHD_Shield-B_Mask.gbr, GBAHD_Shield-B_Paste.gbr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]
2022-03-19 rebuilt the gnd-plane as there was a bridge
    [GBAHD_Shield.kicad_pcb]
2022-03-26 - Fix Github Action - Fix Bluepad config - Enhance OTA View - Speedup FPGA Loading - Fix Changelog - Fix Buttonmapping for X / Y - Add hostname to wifi config - Force shield update with offline update
    [bitstream_handler.cpp, web_handler.cpp]
2022-09-29 - Fix sudden reboots - Add support for more controllers (update BluePad32 to 3.5.1) - Add support for Consoles4You gbaHD shields
    [bitstream_handler.cpp, debug.h, global.h]
2022-12-05 Fix C4You Shield Compatibility
    [global.h]
2023-04-04 Fix C4Y Shield - for real this time
    [global.h]
